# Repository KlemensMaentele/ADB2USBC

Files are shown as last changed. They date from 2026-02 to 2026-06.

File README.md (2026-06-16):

# ADB2USBC

**ADB-to-USB Converter for Apple Desktop Bus Keyboards**

ADB2USBC is a small PCB that allows vintage Apple ADB keyboards to be used as modern USB HID keyboards. The board is built around an ATmega32U2 microcontroller and is intended to run the ADB-to-USB converter firmware from the TMK Keyboard Firmware project.

## Overview

This project contains the hardware design files for an ADB-to-USB converter board.

Features:

* Supports Apple Desktop Bus (ADB) keyboards
* USB HID keyboard output
* ATmega32U2 microcontroller
* Compatible with TMK's ADB-to-USB converter firmware
* USB DFU bootloader support for firmware flashing

## Firmware

This repository does not include firmware.

The board is designed to run the ADB-to-USB converter implementation provided by the TMK Keyboard Firmware project:

TMK Keyboard Firmware:
https://github.com/tmk/tmk_keyboard

Please refer to the TMK documentation for building and flashing firmware.

## Hardware

The repository contains:

* KiCad project files
* Schematic
* Bill of Materials (BOM)
* Custom footprint, symbol and 3D model files for the ADB connector

### BOM

A Bill of Materials (BOM) is included for assembly. The provided BOM was created specifically for JLCPCB assembly services and includes the manufacturer part numbers used for the original build. Component availability may change over time, so substitutions may be required.

### Manufacturing

Gerber files are not included in this repository. They can be easily generated from the included KiCad project files using KiCad's built-in fabrication output tools.

### ISP Header

The board includes a standard 6-pin Atmel ISP header for development and debugging purposes.

For normal operation, the ISP header is not required. The ATmega32U2 can be programmed via its USB DFU bootloader, so the header may be removed.

## Pictures

### Assembled Board

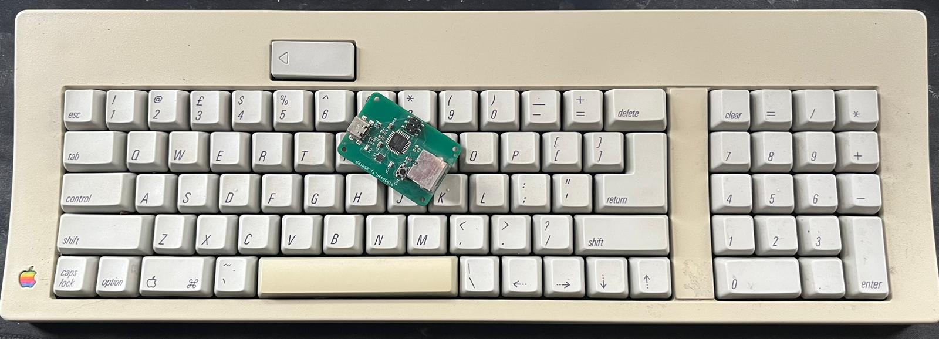
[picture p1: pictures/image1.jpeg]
ADB2USBC Board-1

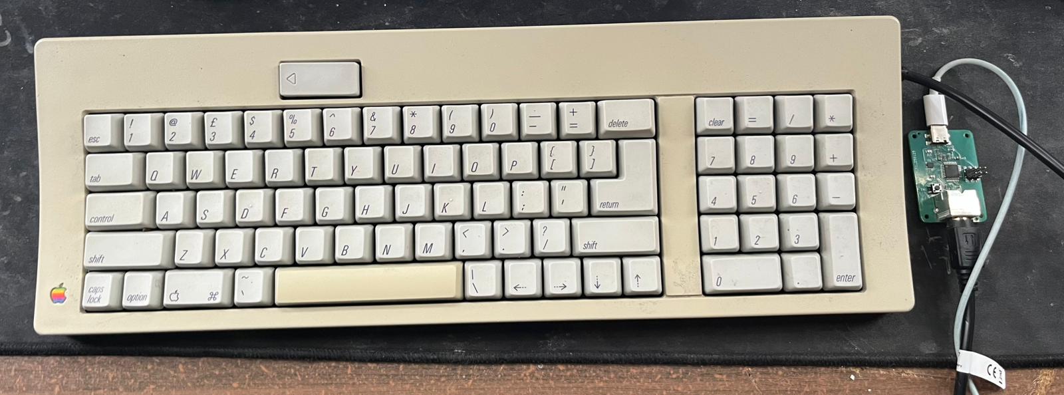
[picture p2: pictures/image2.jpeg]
ADB2USBC Board-2


### PCB
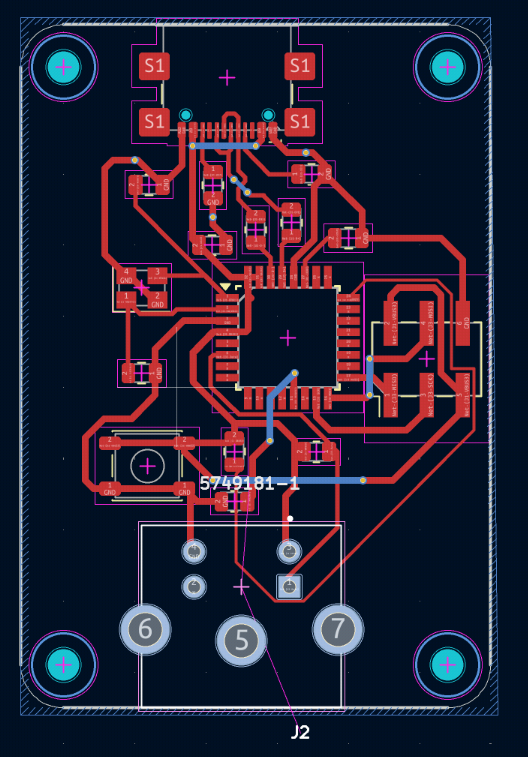
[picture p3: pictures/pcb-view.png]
ADB2USBC PCB

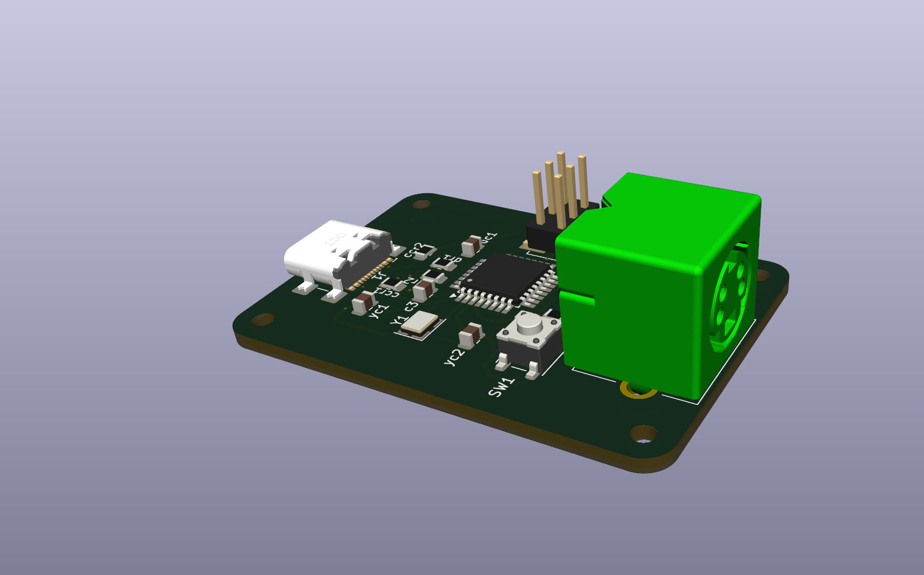
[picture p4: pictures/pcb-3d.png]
ADB2USBC PCB-3D


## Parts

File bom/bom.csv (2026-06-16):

Comment | Designator | Footprint | JLCPCB Part
10uf | c3 | Capacitor_SMD:C_0805_2012Metric
5k1 | ccr1 ccr2 | Resistor_SMD:R_0805_2012Metric
22 | dr1 dr2 | Resistor_SMD:R_0805_2012Metric
USB4110-GF-A | J1 | Connector_USB:USB_C_Receptacle_GCT_USB4110
5749181-1 | J2 | Library:57491811
AVR-ISP-6 | J3 | Connector_PinHeader_2.54mm:PinHeader_2x03_P2.54mm_Vertical_SMD
10k | R1 R2 | Resistor_SMD:R_0805_2012Metric
1k | R3 | Resistor_SMD:R_0805_2012Metric
SW_DPST_x2 | SW1 | Button_Switch_SMD:SW_SPST_PTS647_Sx38
ATmega32U2-A | U1 | Package_QFP:TQFP-32_7x7mm_P0.8mm
1uf | uc1 | Capacitor_SMD:C_0805_2012Metric
Crystal_GND24 | Y1 | Crystal:Crystal_SMD_Abracon_ABM8G-4Pin_3.2x2.5mm
26pf | yc1 yc2 | Capacitor_SMD:C_0805_2012Metric

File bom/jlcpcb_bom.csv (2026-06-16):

Reference | Product | quantity
c3 | CL21A106KQFNNNE | 1
ccr1,ccr2 | ERJ-6ENF5101V | 2
dr1,dr2 | CRGCQ0805J22R | 2
J1 | USB4110-GF-A | 1
J2 | 5749181-1 | 1
J3 | 10129383-906002BLF | 1
R1,R2 | CRCW080510K0JNEC | 2
R3 | RMCF0805FG1K00 | 1
SW1 | PTS647SM38SMTR2 LFS | 1
U1 | ATMEGA32U2-AU | 1
uc1 | 0805B105J100CT | 1
Y1 | ABM8G-16.000MHZ-18-D2Y-T | 1
yc1,yc2 | 0805N250K500CT | 2

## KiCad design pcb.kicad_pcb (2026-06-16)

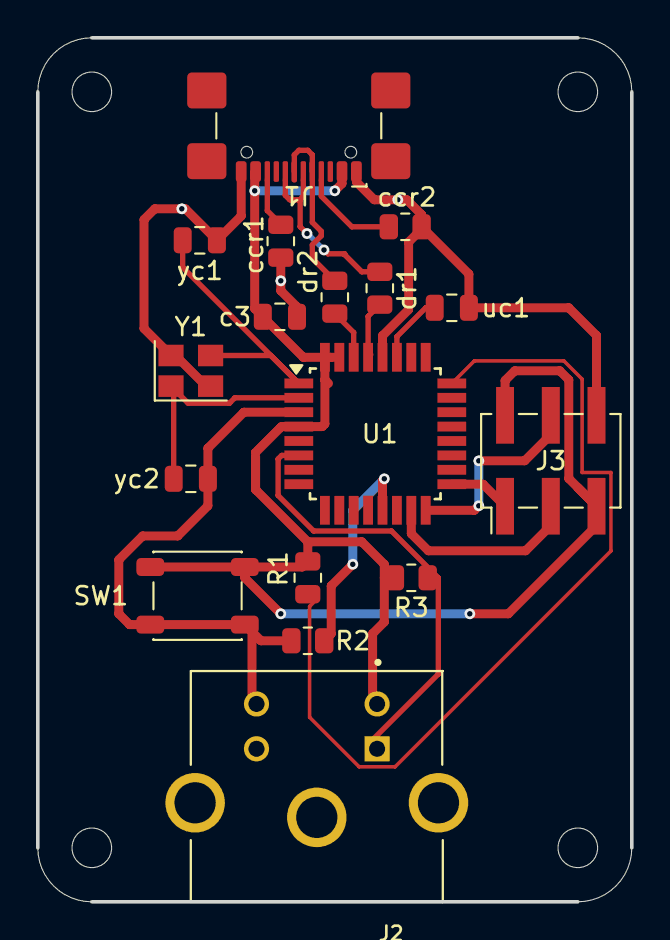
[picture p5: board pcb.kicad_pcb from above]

Board: 2 copper layers, 33.0 x 48.0 mm, 21 parts (0 on the bottom side), 17 nets.

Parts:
H1, H2, H3, H4: MountingHole; MountingHole_2.2mm_M2
J1: USB4110-GF-A; USB_C_Receptacle_GCT_USB4110
J2: 5749181-1
J3: AVR-ISP-6; PinHeader_2x03_P2.54mm_Vertical_SMD
R1, R2: 10k; R_0805_2012Metric
R3: 1k; R_0805_2012Metric
SW1: SW_DPST_x2; SW_SPST_PTS647_Sx38
U1: ATmega32U2-A; TQFP-32_7x7mm_P0.8mm
Y1: Crystal_GND24; Crystal_SMD_Abracon_ABM8G-4Pin_3.2x2.5mm
c3: 10uf; C_0805_2012Metric
ccr1, ccr2: 5k1; R_0805_2012Metric
dr1, dr2: 22; R_0805_2012Metric
uc1: 1uf; C_0805_2012Metric
yc1, yc2: 26pf; C_0805_2012Metric

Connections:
GND: J1.A1 (GND_1), J1.A12 (GND), J1.B1 (GND), J1.B12 (GND), J2.4 (GND), J3.6 (GND), R2.2, SW1.1 (A), U1.3 (GND), U1.28 (UGND), Y1.2, Y1.4, c3.1, ccr1.2, ccr2.2, uc1.1, yc1.1, yc2.1
unnamed: J1.A5 (CC1), ccr2.1
unnamed: J1.B5 (CC2), ccr1.1
unnamed: J1.A7 (DN1), J1.B7 (Dn2), dr2.2
unnamed: J1.A6 (DP1), J1.B6 (DP2), dr1.2
unnamed: J1.A4 (VBus1), J1.A9 (VBus2), J1.B4 (VBUS3), J1.B9 (VBus4), J2.3 (VCC), J3.2 (VCC), J3.5 (~RST), R1.2, R3.2, SW1.2 (B), U1.4 (VCC), U1.31 (UVCC), U1.32 (AVCC), c3.2
unnamed: J2.1 (Data), R3.1, U1.6 (PD0)
unnamed: J3.1 (MISO), U1.17 (PB3)
unnamed: J3.4 (MOSI), U1.16 (PB2)
unnamed: J3.3 (SCK), U1.15 (PB1)
unnamed: U1.29 (D+), dr1.1
unnamed: U1.30 (D-), dr2.1
unnamed: U1.2 (PC0/XTAL2), Y1.1, yc2.2
unnamed: R1.1, U1.24 (PC1/~RESET)
unnamed: U1.27 (UCAP), uc1.2
unnamed: U1.1 (XTAL1), Y1.3, yc1.2
unnamed: R2.1, U1.13 (~HWB/PD7)

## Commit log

2026-06-16 change structure
    [bom.csv, manufacturer_bom.csv, pcb.kicad_pcb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]
2026-06-16 Fix pcb dcm errors
    [pcb.kicad_pcb, pcb.kicad_sch]
2026-06-16 Revise README for clarity on project components
    Updated README to clarify project files and BOM details.
2026-06-16 Change bom name
    [jlcpcb_bom.csv]
